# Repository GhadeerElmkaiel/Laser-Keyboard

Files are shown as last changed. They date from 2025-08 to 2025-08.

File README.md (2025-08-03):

# How to Build a Keyboard with Lasers

## 🔗 YouTube Videos

### ▶️ English version  
Watch the video (https://youtu.be/89x4z27nNDk)

### ▶️ Arabic version  
Watch the video (https://youtu.be/areOqmaQYtU)

---

## 🖼️ The keyboard layout

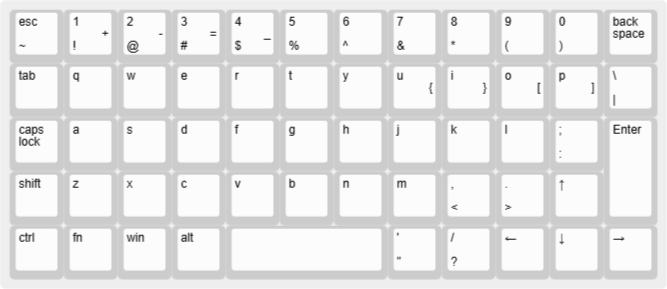
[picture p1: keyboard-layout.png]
Keyboard Project


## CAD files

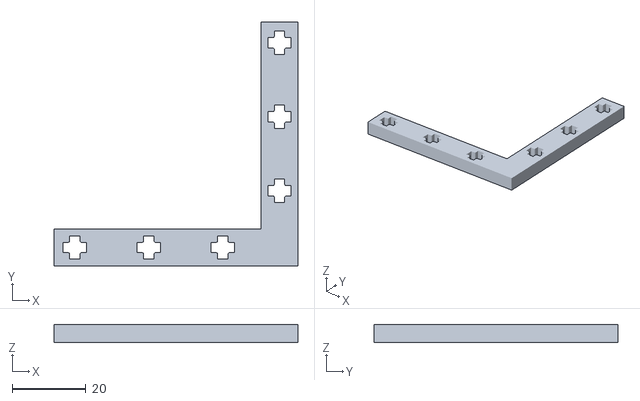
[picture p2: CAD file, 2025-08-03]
Designs and files/3D printing files/Alignment/small_kb_base_v2.stl
66.0 x 66.0 x 5.00

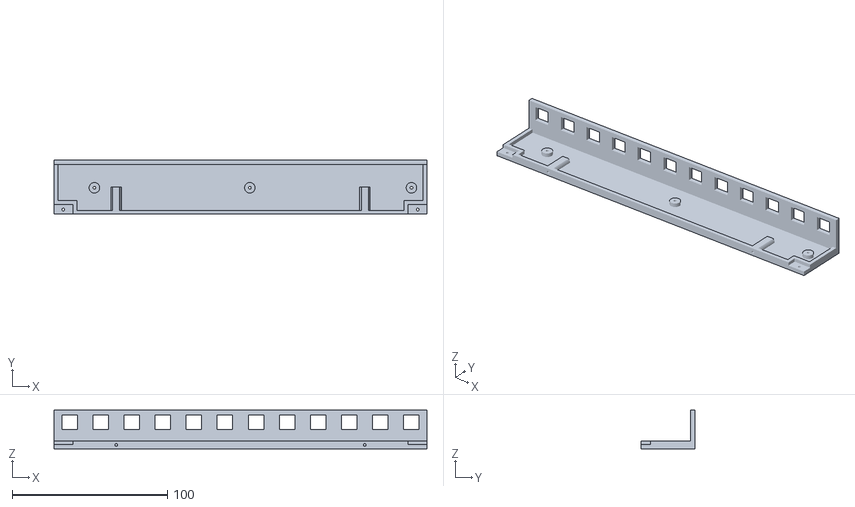
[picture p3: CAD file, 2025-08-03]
Designs and files/3D printing files/Keyboard parts/top_part.stl
240.0 x 35.0 x 24.8

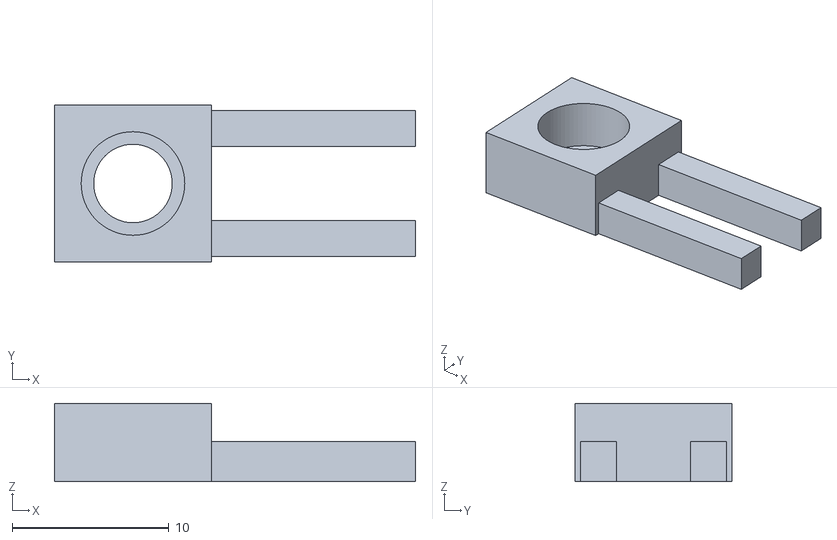
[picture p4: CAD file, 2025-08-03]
Designs and files/3D printing files/Testing/Laser_testing_laser_hoder v5.stl
23.0 x 10.0 x 5.00

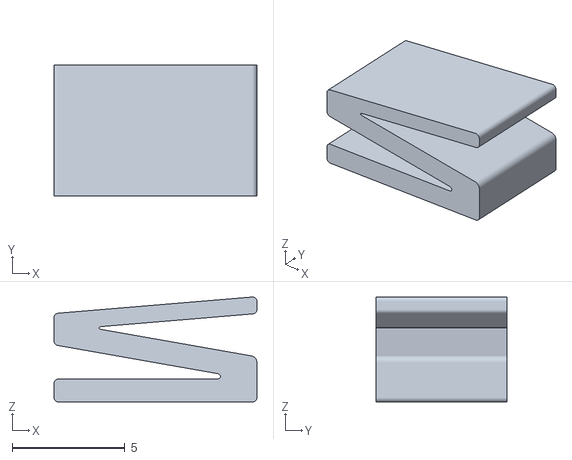
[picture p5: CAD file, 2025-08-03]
Designs and files/3D printing files/Alignment/laser_alignment_part.stl
9.00 x 5.80 x 4.65

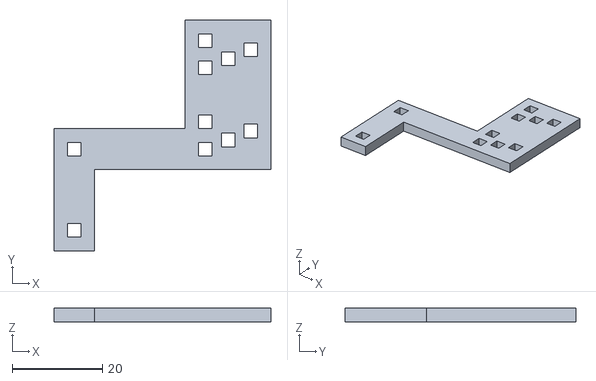
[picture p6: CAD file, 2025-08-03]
Designs and files/3D printing files/Testing/Laser_testing_sensor_base v3.stl
48.0 x 51.0 x 3.00

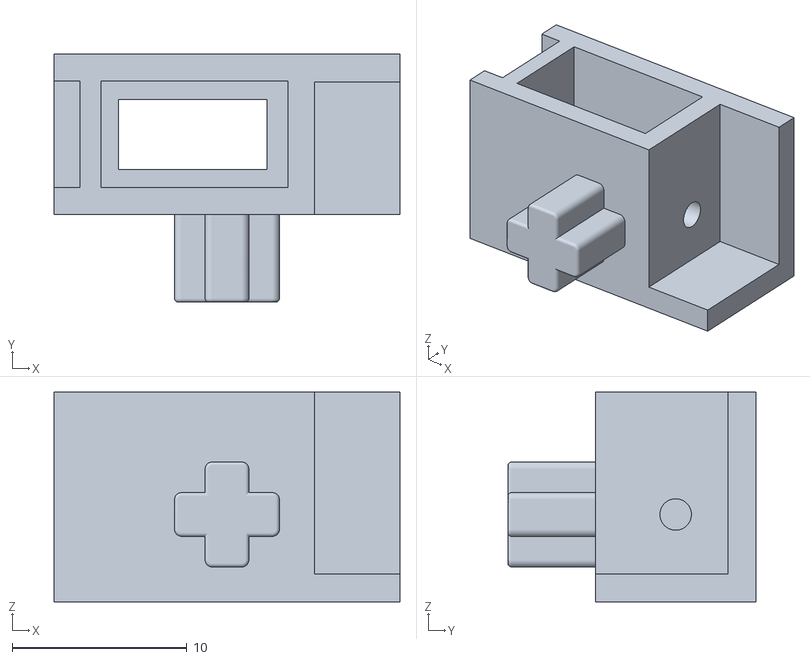
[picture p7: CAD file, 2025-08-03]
Designs and files/3D printing files/Alignment/laser_holder-V5.stl
19.8 x 14.2 x 12.0

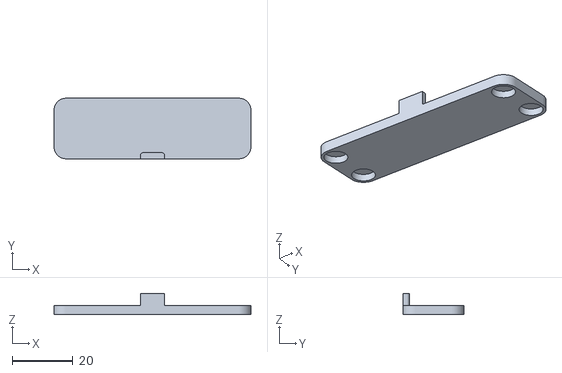
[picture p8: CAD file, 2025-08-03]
Designs and files/3D printing files/Keyboard parts/battery_cover.stl
65.0 x 20.0 x 7.00

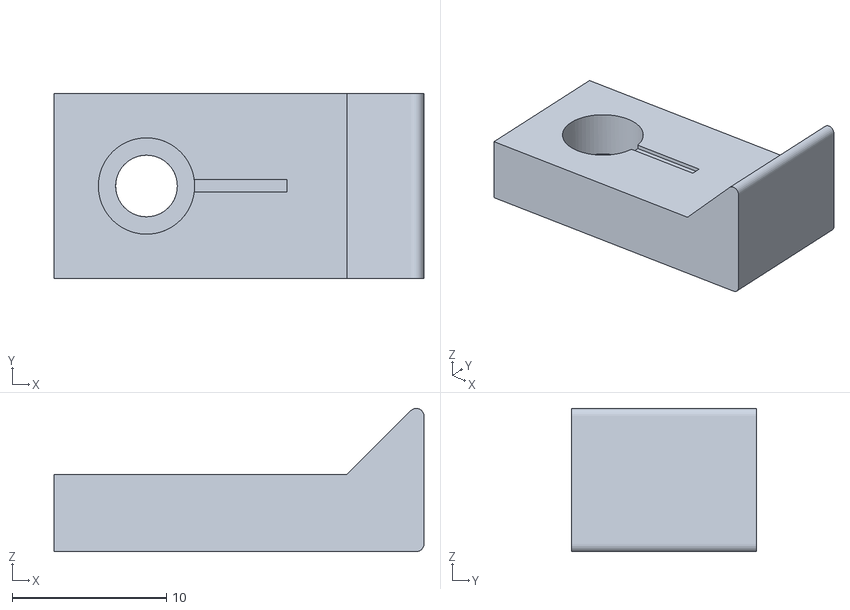
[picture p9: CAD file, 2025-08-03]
Designs and files/3D printing files/Testing/Laser_holder_slider v1.stl
24.0 x 12.0 x 9.29

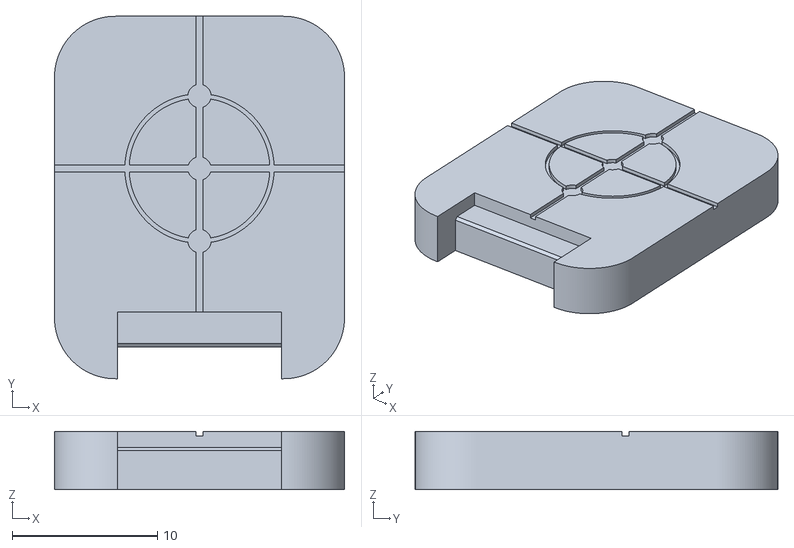
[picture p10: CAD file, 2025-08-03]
Designs and files/3D printing files/Alignment/alignment_back-V2.stl
20.0 x 25.0 x 4.00

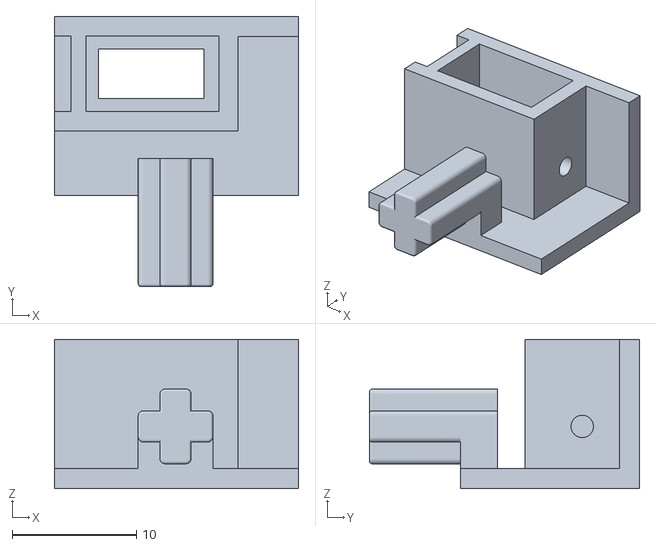
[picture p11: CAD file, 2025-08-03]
Designs and files/3D printing files/Keyboard parts/Laser_holder.stl
19.6 x 21.7 x 12.0

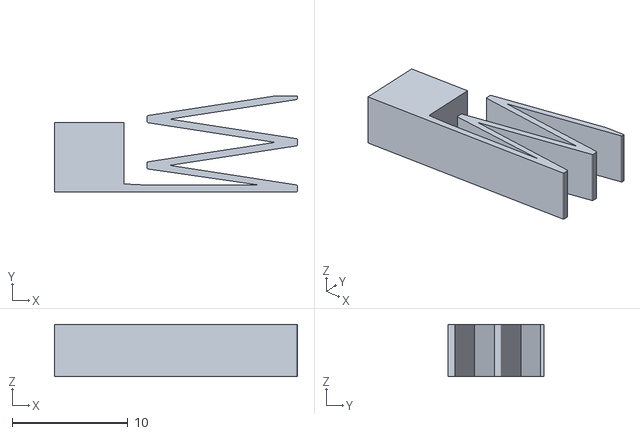
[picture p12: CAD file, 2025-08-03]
Designs and files/3D printing files/Testing/alignement_part_test_v2.stl
21.0 x 8.30 x 4.50

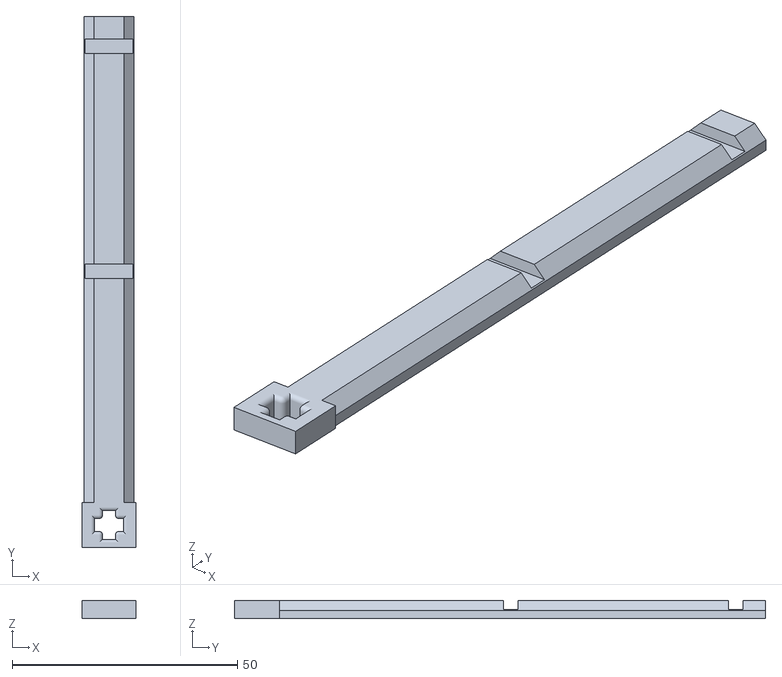
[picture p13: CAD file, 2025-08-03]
Designs and files/3D printing files/Alignment/alignment_base-V3.stl
12.0 x 118.0 x 4.00

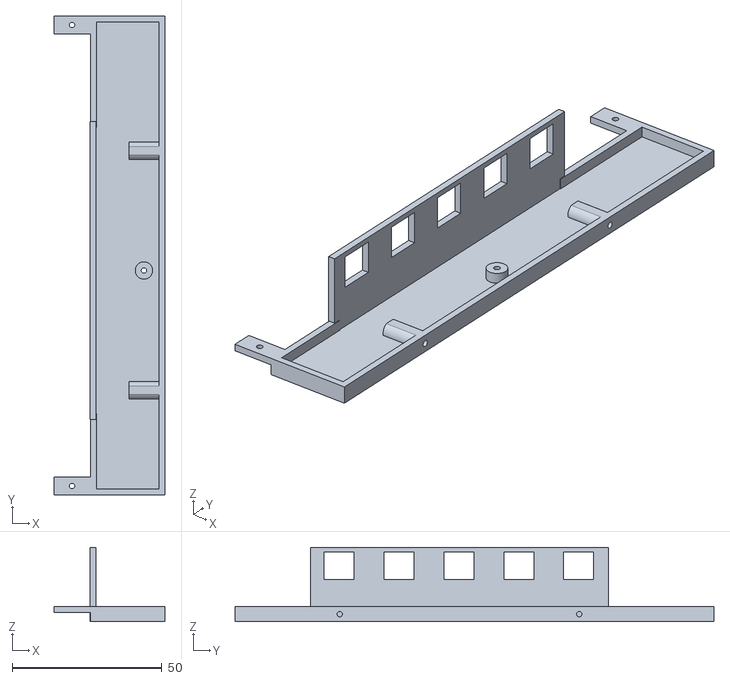
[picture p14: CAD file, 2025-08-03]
Designs and files/3D printing files/Keyboard parts/sensor_side_base.stl
37.0 x 160.0 x 24.8

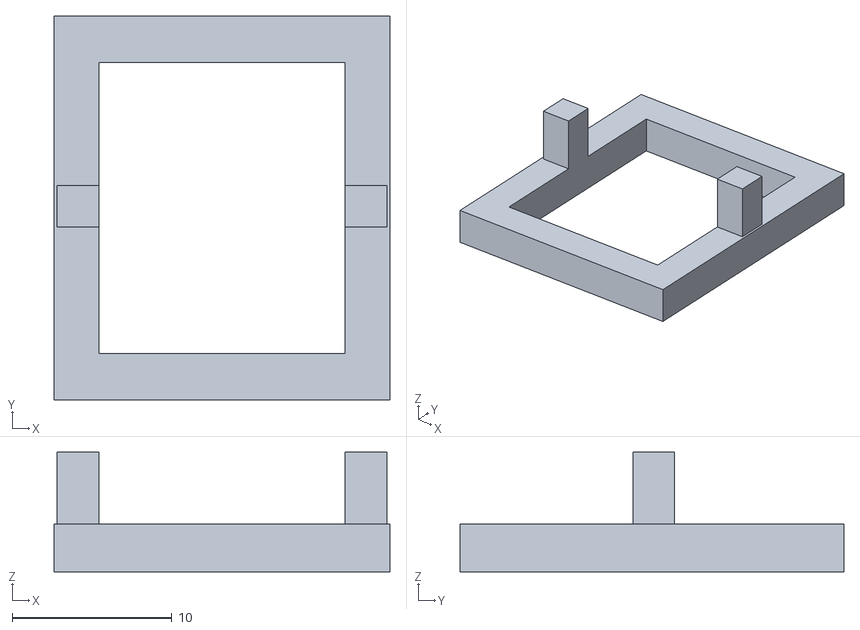
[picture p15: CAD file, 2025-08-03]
Designs and files/3D printing files/Testing/Laser_testing_sensor_holder_v3.stl
21.0 x 24.0 x 7.50

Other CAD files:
Designs and files/3D printing files/Keyboard parts/lower_base.stl
Designs and files/3D printing files/Testing/Laser_testing_laser_hoder.stl
Designs and files/3D printing files/Keyboard parts/laser_side_base.stl
Designs and files/3D printing files/Keyboard parts/bottom_laser_cover.stl
Designs and files/3D printing files/Keyboard parts/side_wall_L.stl
Designs and files/3D printing files/Keyboard parts/side_wall_R.stl
Designs and files/3D printing files/Keyboard parts/top_wall.stl
Designs and files/3D printing files/Testing/3x3_KB_test.stl
Designs and files/3D printing files/Testing/Laser_slider_base v1.stl
Designs and files/3D printing files/Testing/laser_hall_test v1.stl

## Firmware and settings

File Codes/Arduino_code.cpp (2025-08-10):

#include <Adafruit_GFX.h>
#include <Adafruit_SSD1306.h>
#include <SoftwareSerial.h>

SoftwareSerial BT(8, 7); // RX = D8 (from TX of Bluetooth), TX = D7 (to RX of Bluetooth)

#define SCREEN_WIDTH 128
#define SCREEN_HEIGHT 32
#define SCREEN_I2C_ADDRESS 0x3c
#define OLED_RESET_PIN -1

Adafruit_SSD1306 screen(SCREEN_WIDTH, SCREEN_HEIGHT, &Wire, OLED_RESET_PIN);


// Input pins
const int muxPins[] = {3, 4, 5, 6};
const int CAPS_PIN = 13;
bool Caps= false;
bool prevCapsKeyState = false; // To track "caps" key previous state
bool debuggingMode = true; // To define if the display shows debugging information
bool startKB = false; // To start the KB 


// Define row and column pins

const int numRows = 5;
const int numCols = 12;
// Maping between the rows / cols number and the corresponding pin on the multiplexer
const int rowMuxPins[numRows] = {0, 1, 2, 3, 4};
const int colMuxPins[numCols-1] = {5, 6, 7, 8, 13, 14, 15, 12, 11, 10, 9};
// The first collumn is not on the multiplex and connected directly to the Arduino via pin 9
const int COL_0_PIN = 9;
// The pin of the mux signal
const int MUX_SIG_PIN = 10;

bool rowPressed[numRows] = {false, false, false, false, false};
bool colPressed[numCols] = {false, false, false, false, false, false, false, false, false, false, false, false};

// Key mapping based on (row, col)
const char* keyMap[5][12] = {
  {"esc", "1", "2", "3", "4", "5", "6", "7", "8", "9", "0", "backspace"},
  {"tab", "q", "w", "e", "r", "t", "y", "u", "i", "o", "p", "\\"},
  {"caps", "a", "s", "d", "f", "g", "h", "j", "k", "l", ";", "enter"},
  {"shift", "z", "x", "c", "v", "b", "n", "m", ",", ".", "Up", "enter"},
  {"ctrl", "fn", "win", "alt", "space", "space", "space", "'", "/", "Left", "Down", "Right"}
};
void setup() {
  BT.begin(9600); // Bluetooth module

  // The pins connected to the multiplexer (sellection pins)
  for (int i = 0; i < 4; i++) {
    pinMode(muxPins[i], OUTPUT);
  }

  pinMode(MUX_SIG_PIN, INPUT);
  // // Set row and column pins as input
  // for (int i = 0; i < 3; i++) {
  //   pinMode(rowPins[i], INPUT);
  //   pinMode(colPins[i], INPUT);
  // }
  pinMode(CAPS_PIN, OUTPUT);
  digitalWrite(CAPS_PIN, LOW);

  // Initialize OLED
  if (!screen.begin(SSD1306_SWITCHCAPVCC, 0x3C)) {
    Serial.println(F("SSD1306 allocation failed"));
    while (true);
  }

  screen.clearDisplay();
  screen.setTextSize(2);
  screen.setTextColor(SSD1306_WHITE);
  screen.setCursor(0, 10);
  screen.print("Ready");
  screen.display();
  delay(1000);
  screen.setTextSize(2);
}


// Set 4-bit multiplexer address (0–15)
void selectMuxChannel(uint8_t channel) {
  for (int i = 0; i < 4; i++) {
    digitalWrite(muxPins[i], (channel >> i) & 0x01);
  }
}

void loop() {
  // Keys for commands
  bool FnPressed = false;
  bool altPressed = false;
  bool dPressed = false;
  bool nPressed = false;

  screen.clearDisplay();
  screen.setCursor(0, 0);
  // Read the rows value
  for(int row_iter = 0; row_iter< numRows; row_iter++){
    int channel = rowMuxPins[row_iter];
    selectMuxChannel(channel);
    // delay(1);
    int rowState = digitalRead(MUX_SIG_PIN);
    rowPressed[row_iter] = (rowState == HIGH);
  }

  // === Read COLUMN 0 (direct connection) ===
  colPressed[0] = (digitalRead(COL_0_PIN) == HIGH);

  // Read the cols value
  for(int col_iter = 0; col_iter< numCols; col_iter++){
    int channel = colMuxPins[col_iter];
    selectMuxChannel(channel);
    // delay(1);
    int colState = digitalRead(MUX_SIG_PIN);
    colPressed[col_iter + 1] = (colState == HIGH);  // +1 because col 0 is already read
  }

  // === Format string ===
  // In the case of debugging show the rows and cols detected
  if(debuggingMode)
    screen.print("R:");
  String msg = "R: ";
  for (int i = 0; i < numRows; i++) {
    if (rowPressed[i]) {
      msg += String(i) + " ";
      if(debuggingMode){
        screen.print(i);
        screen.print(",");
      }
    }
  }

  if(debuggingMode)
    screen.print("C:");
  msg += ", C: ";
  for (int i = 0; i < numCols; i++) {
    if (colPressed[i]) {
      msg += String(i) + " ";
      if(debuggingMode){
        screen.print(i);
        screen.print(",");
      }
    }
  }
  
  // In the case of debugging print the key pressed on the second line
  if(debuggingMode)
    screen.setCursor(0, 16);

  // === Send message via Bluetooth if the startKB is true ===
  if(startKB){
    BT.println(msg);
  }

  bool keyShown = false;
  bool currentCapsKeyState = false;
  for (int row = 0; row < numRows; row++) {
    for (int col = 0; col < numCols; col++) {
      if (rowPressed[row] && colPressed[col]) {
        const char* key = keyMap[numRows - row - 1][numCols - col - 1];
        if (strcmp(key, "fn") == 0) FnPressed = true;
        if (strcmp(key, "alt") == 0) altPressed = true;
        if (strcmp(key, "d") == 0) dPressed = true;
        if (strcmp(key, "n") == 0) nPressed = true;
        screen.println(key);
        keyShown = true;

        if (strcmp(key, "caps") == 0) {
          currentCapsKeyState = true;  // caps key is pressed now
        }
      }
    }
  }


  screen.display();
  
  // === Edge detection for caps key ===
  if (currentCapsKeyState && !prevCapsKeyState) {
    Caps = !Caps;
    digitalWrite(CAPS_PIN, Caps ? HIGH : LOW);
  }

  prevCapsKeyState = currentCapsKeyState;
  
  // === Checking for commands ===

  // Tuggeling debugging mode
  // Ctrl+Alt+D 
  if (FnPressed && altPressed && dPressed) {
    debuggingMode = !debuggingMode;
    screen.clearDisplay();
    screen.setCursor(0, 0);
    if(debuggingMode)
      screen.println("Debugging on");
    else
      screen.println("Debugging off");
    screen.display();
    delay(1000);
  }
    
  // Start/Stop sending via Bluetooth
  // Ctrl+Alt+S
  if (FnPressed && altPressed && nPressed) {
    startKB = !startKB;
    screen.clearDisplay();
    screen.setCursor(0, 0);
    if(startKB)
      screen.println("Start Sending");
    else
      screen.println("Stop sending");
    screen.display();
    delay(1000);
  }

}

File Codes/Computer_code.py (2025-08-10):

import serial
import time
import keyboard

# Define the keyboard layout matrix
key_matrix = [
    ['esc', '1', '2', '3', '4', '5', '6', '7', '8', '9', '0', 'backspace'],
    ['tab', 'q', 'w', 'e', 'r', 't', 'y', 'u', 'i', 'o', 'p', '\\'],
    ['capslock', 'a', 's', 'd', 'f', 'g', 'h', 'j', 'k', 'l', ';', 'enter'],
    ['shift', 'z', 'x', 'c', 'v', 'b', 'n', 'm', ',', '.', 'up', 'enter'],
    ['ctrl', 'fn', 'win', 'alt', ' ', ' ', ' ', "'", '/', 'left', 'down', 'right']
]

# === Settings ===
PORT = 'COM3' # Use your port to which the Bluetooth module is connected, for example 'COM3'
BAUDRATE = 9600
MISSED_THRESHOLD = 3  # messages before releasing key
debug_mode = False # True

held_keys = {}  # (row, col) -> missed_count
prev_rows = []
prev_cols = []

# Connect to Bluetooth serial
ser = serial.Serial(PORT, BAUDRATE, timeout=0.01)
time.sleep(2)

# === Helpers ===
def get_key(row, col):
    max_r = len(key_matrix)
    max_c = len(key_matrix[0])
    if 0 <= row < max_r and 0 <= col < max_c:
        return key_matrix[max_r - row - 1][max_c - col - 1]
    return None

key_aliases = {
    ' ': 'space',
    '\\': 'backslash',
    'win': 'windows',
    'capslock': 'caps lock',
}

def normalize_key(key):
    return key_aliases.get(key, key)

def smart_key_detection_simple(prev_rows, prev_cols, curr_rows, curr_cols):
    new_keys = set()

    new_rows = set(curr_rows) - set(prev_rows)
    new_cols = set(curr_cols) - set(prev_cols)
    
    if len(new_rows) > 0 or len(new_cols) > 0:
        print(f"New rows: {new_rows}, New cols: {new_cols}")

    if len(new_rows) > 0 and len(new_cols) > 0:
        for r in new_rows:
            for c in new_cols:
                new_keys.add((r, c))
    elif len(new_rows) > 0:
        for r in new_rows:
            for c in prev_cols:
                new_keys.add((r, c))
    elif len(new_cols) > 0:
        for c in new_cols:
            for r in prev_rows:
                new_keys.add((r, c))

    return new_keys

def parse_message(message):
    try:
        if "R:" not in message or "C:" not in message:
            return [], [], False

        row_part, col_part = message.strip().split(', ')
        rows = row_part.replace('R: ', '').strip()
        cols = col_part.replace('C: ', '').strip()

        row_list = list(map(int, rows.split())) if rows else []
        col_list = list(map(int, cols.split())) if cols else []

        return row_list, col_list, True
    except ValueError:
        return [], [], True

def press_key(key):
    try:
        key = normalize_key(key)
        keyboard.press(key)
        print(f"Holding: {key}")
    except Exception as e:
        print(f"Error pressing {key}: {e}")

def release_key(key):
    try:
        key = normalize_key(key)
        keyboard.release(key)
        print(f"Released: {key}")
    except Exception as e:
        print(f"Error releasing {key}: {e}")

# === Main Loop ===
print("Listening for Bluetooth messages...")
while True:
    line = ser.readline().decode('utf-8').strip()

    curr_rows, curr_cols, is_valid = parse_message(line)
    if not is_valid:
        continue
    
    now = time.time()

    if debug_mode:
        if "R" not in line or "C" not in line:
            continue
        print("Received:", line)

    # --- Handle full keyboard disable
    if len(curr_rows) == 5 or len(curr_cols) == 12:
        print("Skipping message with full row/column data. Keyboard is off.")
        continue
    if len(curr_rows) > 2 or len(curr_cols) > 2:
        print("Skipping message with too many row/column data.")
        continue

    # --- Always update held_keys regardless of whether message changed
    detected_keys = {(r, c) for r in curr_rows for c in curr_cols}
    for key_pos in list(held_keys.keys()):
        if key_pos in detected_keys:
            held_keys[key_pos]['missed'] = 0
        else:
            held_keys[key_pos]['missed'] += 1
        # Release key if held for too long
        held_duration = now - held_keys[key_pos]['press_time']
        if held_duration > 2.0 or held_keys[key_pos]['missed'] >= MISSED_THRESHOLD:
            key = get_key(*key_pos)
            release_key(key)
            del held_keys[key_pos]

    # --- Detect and press new keys
    new_keys = smart_key_detection_simple(prev_rows, prev_cols, curr_rows, curr_cols)
    for (r, c) in new_keys:
        key = get_key(r, c)
        if key and (r, c) not in held_keys:
            press_key(key)
            held_keys[(r, c)] = {'missed': 0, 'press_time': now}

    # --- Update previous state
    prev_rows = curr_rows
    prev_cols = curr_cols
